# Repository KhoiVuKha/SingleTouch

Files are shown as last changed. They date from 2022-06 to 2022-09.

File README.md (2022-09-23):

# SingleTouch
- This project using Capacitive Sensor buttons to capture human touch (ADC values).
- These ADC values are read by some chip's ADC Pins.
- Each Sensor button is configured as a keyboard's key.
- STM32C8T6 processes touch evens and send it to a Computer through USB connection.
- So our product now acts as an USB HID (USB human interface device class) (In another words It is 'a simple keyboard USB version', each sensor button is a key button).
- With this product, we can play many basic games like: Piano (8 keys), Chicken invaders, Pacman...
Some Images:

# Schematic & PCB:
## Schematic


## PCB
Top Layer | Bottom Layer
--|--
 | 

# Product's real Image
- Product is simply as a PCB board with main chip (STM32C8T6 - with intergrated USB interface) and some holes (Capacitive Sensor Buttons)

| Green PCB (v1.0)  | Red PCB (V1.1) |
| --- | --- |
|  | b635873c06c9c2979bd8 |

- Game Pad

TAY_CAM

- Connected with wires connected to objects

| #  | # |
| --- | --- |
|   |   |
|   |   |
|   |   |

# Techniques / Technologies
- Capacitive Sensor Button

  A capacitive sensor is an electronic device that can detect solid or liquid targets without physical contact. To detect these targets, capacitive sensors emit an electrical field from the sensing end of the sensor. Any target that can disrupt this electrical field can be detected by a capacitive sensor

<p align="center">
  
</p>

- Capacitive sensing

  In electrical engineering, capacitive sensing is a technology, based on capacitive coupling, that can detect and measure anything that is conductive or has a dielectric different from air. Refer to [Wiki](https://en.wikipedia.org/wiki/Capacitive_sensing).

- Hardware design.
- C Programming Language.
- USB HID programming.
- Embedded C & STM32 MicroController: ADC, UART, USB, GPIO...
- Probability statistics theory.

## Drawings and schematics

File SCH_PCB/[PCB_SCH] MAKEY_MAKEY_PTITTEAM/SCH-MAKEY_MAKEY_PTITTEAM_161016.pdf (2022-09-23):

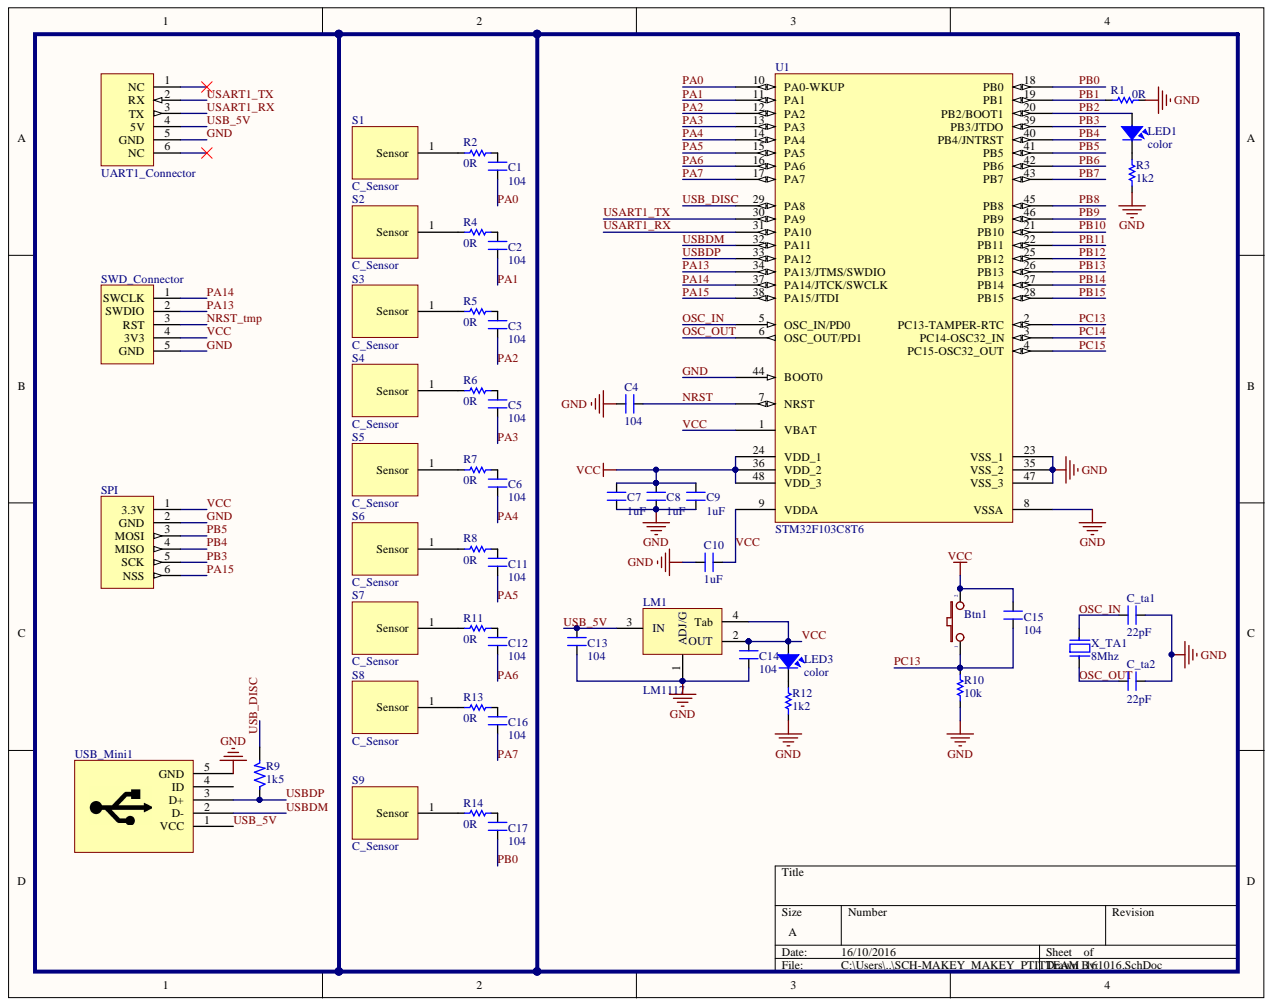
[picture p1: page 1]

3 6 | 3 5
4 8 | 4 7

Size A | Nu m ber | Revisio n

Date: 1 6/1 0/2 0 1 6 | Sheet o f
File: C:\Users\..\SCH-MAKEY_MAKEY_PTITTEAM_ Drawn B1y6: | 1 0 1 6.SchDo c

Comment | Description | Designator | Footprint | LibRef | Quantity
Function | Switch button 2 pin | Btn1 | Button_SMD_2pin | Button_SMD_2pin | 1
104 | Cap SMD, Cap SMD, Cap SMD, Cap SMD, Cap SMD, Cap SMD, Cap SMD, Cremic For Xtal 1pF => 100pF, Cap SMD, Cap SMD, Cap SMD, Cremic For Xtal 1pF => 100pF, Cremic For Xtal 1pF => 100pF | C1, C2, C3, C4, C5, C6, C11, C12, C13, C14, C15, C16, C17 | CAP-0603 | CM, CM, CM, CM, CM, CM, CM, CN0, CM, CM, CM, CN0, CN0 | 13
1uF | Cremic For Xtal 1pF => 100pF, Cremic For Xtal 1pF => 100pF, Cap SMD, Cap SMD | C7, C8, C9, C10 | CAP-0603 | CN0, CN0, CM, CM | 4
22pF | Cremic For Xtal 1pF => 100pF | C_ta1, C_ta2 | CAP-0603 | CN0 | 2
color | Led smd | LED1, LED3 | LED-0805 | Led_SMD | 2
LM1117 | 3v3 | LM1 | SOT223-4N | LM1117 | 1
0R | Resistor smd 0603 type | R1, R2, R4, R5, R6, R7, R8, R11, R13, R14 | RES-0603 | Res_SMD_0603 | 10
1k2 | Resistor smd 0603 type | R3, R12 | RES-0603 | Res_SMD_0603 | 2
1k5 | Resistor 1/4W | R9 | RES-0603 | R | 1
10k | Resistor smd 0603 type | R10 | RES-0603 | Res_SMD_0603 | 1
C_Sensor | | S1, S2, S3, S4, S5, S6, S7, S8, S9 | SOP2 | C_Sensor | 9
| | SPI | JP6 | SPI_Connector | 1
| | SWD_Connector | JP_5 | Load_Program | 1
STM32F103C8T6 | STM32 ARM-based 32-bit MCU with 64 Kbytes Flash, 48-pin LQFP, Industrial Temperature | U1 | LQFP48_N | STM32F103C8T6 | 1
Connector | Connector to USB2Com module | UART1_Connector | JP6 | USB2Com_Conn | 1
| | USB_Mini1 | Micro_USB | USB_M | 1
8Mhz | Crystal For all Crystal 2piX_TA1 | | XT2 | XT2 | 1

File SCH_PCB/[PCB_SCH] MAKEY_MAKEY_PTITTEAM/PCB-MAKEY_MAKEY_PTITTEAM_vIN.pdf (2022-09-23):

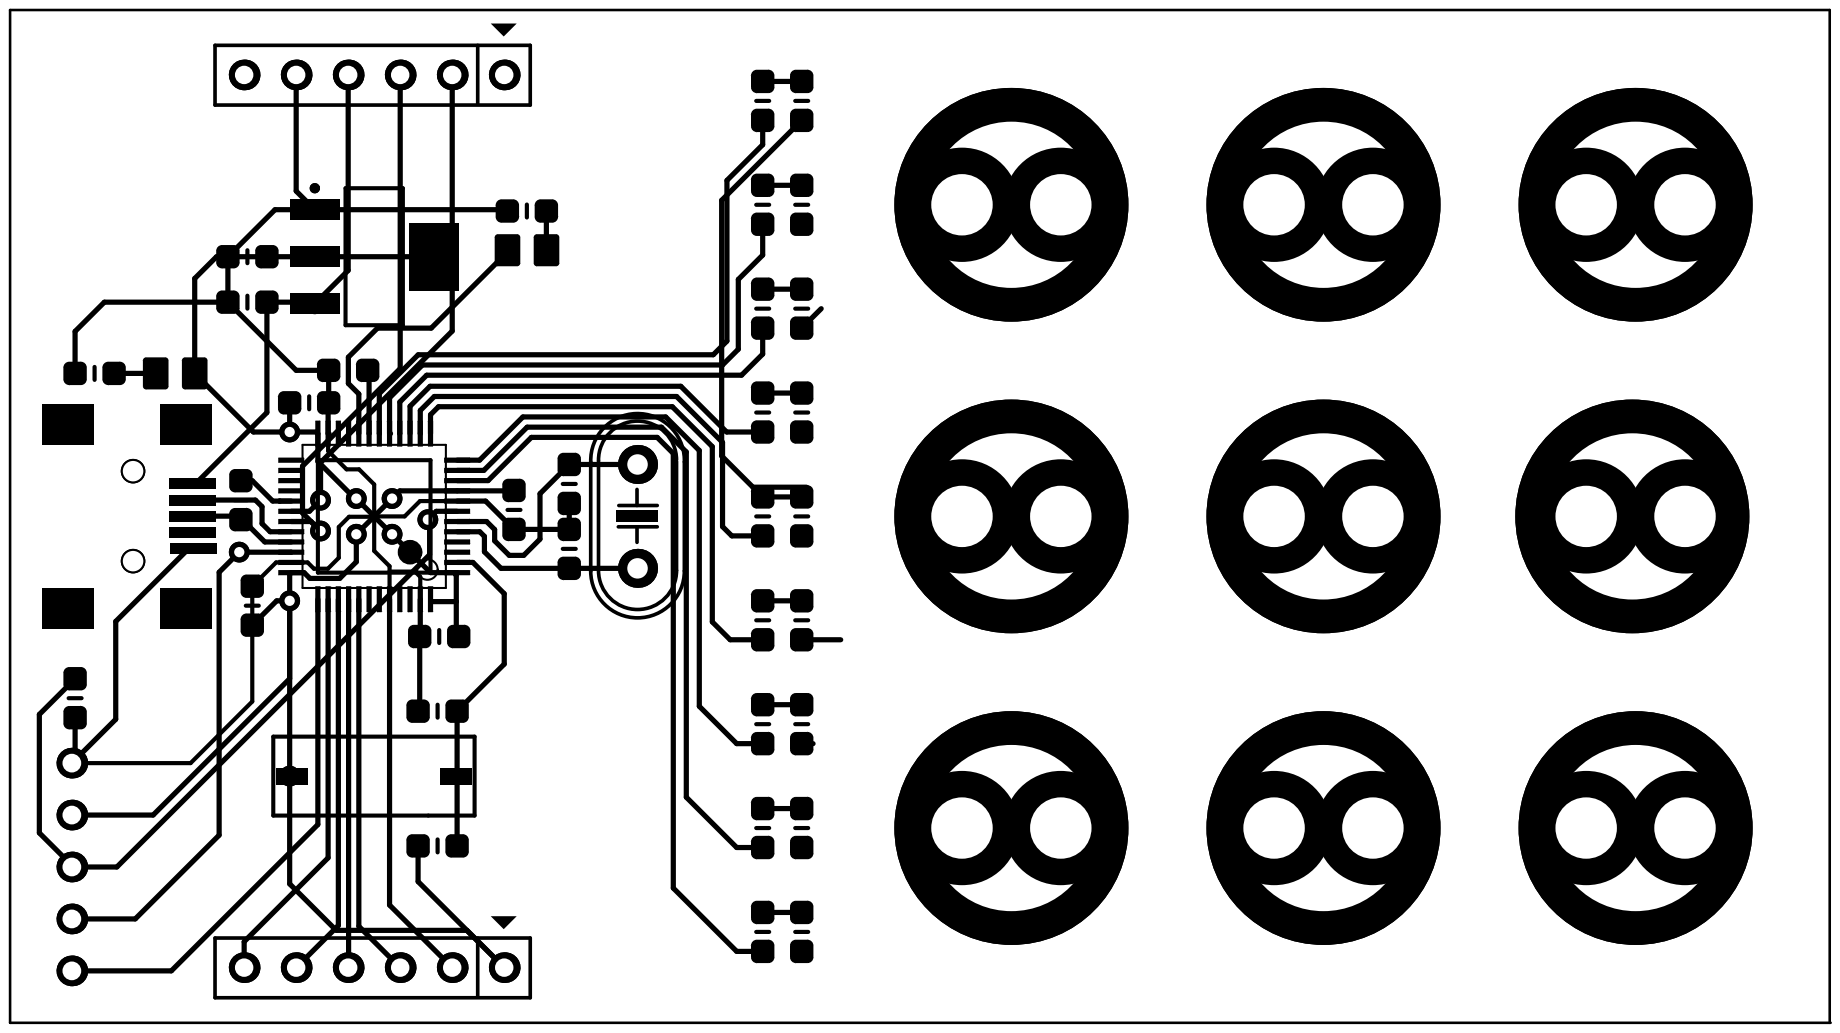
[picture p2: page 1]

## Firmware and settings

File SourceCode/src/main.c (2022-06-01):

/*******************************************************************************************************
  Step    TIM2 event    CCR_VALUE       DMA1    DMA transfer

  1       _UP	          0	              _CH2	  ADC1_JSQR_mem         []  -->  ADC1_JSQR
  2       _CH2	        10	            _CH7	  TIM2_SR_mem           []  -->  TIM2_SR 	        tim2_isr()
  3       _CH1	        200	            _CH5	  GPIOA_CRL_mem         []  -->  GPIOA_CRL
  4       _CH3	        201	            _CH1	  tim2_isr_channel_x_mem[]  -->  tim2_isr_func

                        ARR = 180*2 - 1

                                        _CH4	  channelAccSum         []  -->   channelValue[]
*********************************************************************************************************/
#include <libopencm3/stm32/rcc.h>
#include <libopencm3/stm32/gpio.h>
#include <libopencm3/stm32/usart.h>
#include <libopencm3/stm32/adc.h>
#include <libopencm3/stm32/timer.h>
#include <libopencm3/stm32/flash.h>
#include <libopencm3/cm3/nvic.h>
#include <libopencm3/stm32/dma.h>
#include <libopencm3/cm3/dwt.h>
#include <libopencm3/cm3/scb.h>
#include <libopencm3/cm3/vector.h>

#include <stdio.h>
#include <math.h>

#include "clock.h"
#include "usb.h"
#include "elog.h"
#include "keyboard.h"
#include "keymap.h"
#include "usb_keycode.h"


#define         NOP()                       __asm("nop")
#define         NOP_A()  { /*NOP(); /*NOP(); NOP(); NOP();*/}
#define         NOP_B()  { /*NOP(); NOP(); NOP(); NOP();*/ }
#define         NOP_C()  { /*NOP(); NOP(); NOP(); NOP();*/ }

#define         _FOR_CHANNEL_(inst)         for (int channel = 0; channel < CHANNEL_N; channel++) { inst }

// GPIO Mode define
#define         GPIO_PINMODE(pin, mode)     ((mode) << (((pin) & (8-1))*4))
#define         GPIO_PINMODE_AIN(pin)       GPIO_PINMODE(pin, 0b0000)       // Analog Input
#define         GPIO_PINMODE_IPUD(pin)      GPIO_PINMODE(pin, 0b1000)       // Input Pull-Up or -Down

#define         GPIO_PINMODE_OPP2M(pin)     GPIO_PINMODE(pin, 0b0010)       // Output Push-Pull  2 MHz
#define         GPIO_PINMODE_OPP10M(pin)    GPIO_PINMODE(pin, 0b0001)       // Output Push-Pull 10 MHz
#define         GPIO_PINMODE_OPP50M(pin)    GPIO_PINMODE(pin, 0b0011)       // Output Push-Pull 50 MHz

#define         GPIO_PINMODE_OPP2M_ALL  \
(               GPIO_PINMODE_OPP2M(0)   \
              | GPIO_PINMODE_OPP2M(1)   \
              | GPIO_PINMODE_OPP2M(2)   \
              | GPIO_PINMODE_OPP2M(3)   \
              | GPIO_PINMODE_OPP2M(4)   \
              | GPIO_PINMODE_OPP2M(5)   \
              | GPIO_PINMODE_OPP2M(6)   \
              | GPIO_PINMODE_OPP2M(7)   \
)

#define  GPIO_PINMODE_MASK(pin)      (0b1111 << (((pin) & (8-1))*4))
#define  GPIO_MEASURE_PIN(pin)       (GPIO_PINMODE_AIN(pin) | (GPIO_PINMODE_OPP2M_ALL & ~GPIO_PINMODE_MASK(pin)))

// ADC1 Register define
#define         ADC1_CR2_BASE                  \
(                                              \
                ADC_CR2_ADON                   \
              | ADC_CR2_CONT                   \
              | ADC_CR2_ALIGN_LEFT             \
              | ADC_CR2_EXTSEL_SWSTART         \
              | ADC_CR2_JEXTSEL_JSWSTART       \
              | ADC_CR2_JEXTTRIG               \
)

#define         STAT_N                           (1024L/2)
#define         CALIBRATE_N                      (1024L)
#define         AVERAGE                          (498) // 498
#define         SCALE                            (AVERAGE*8)
#define         CHANNEL_N                        8

#define         THRESHOLD_HI                         10*SCALE       // stm32 pin -> wire -> res 10k -> cap 104 -> thLED
#define         THRESHOLD_LOW                        9*SCALE       // stm32 pin -> wire -> res 10k -> cap 104 -> thLED

// For Timer2
#define         ARR_VALUE                        (180*2-1)        // Thoi gian giua 2 lan nhay vao ngat
#define         PSC_VALUE                        (1*1-1)          // CK_CNT = PCLK / (PSC[15:0] + 1)
// TIM2_CH1
#define         CCR1_VALUE                       200


// TIM2_CH2
#define         CCR2_VALUE                       10
// TIM2_CH3
#define         CCR3_VALUE                       201


//----------------------------------For DMA-------------------------------------
#define         DMA_CCR_SRC_PERIPHERAL            ((uint32_t)(0x00000000))
#define         DMA1_CH1                          DMA1, DMA_CHANNEL1
#define         DMA1_CH2                          DMA1, DMA_CHANNEL2
#define         DMA1_CH4                          DMA1, DMA_CHANNEL4
#define         DMA1_CH5                          DMA1, DMA_CHANNEL5
#define         DMA1_CH7                          DMA1, DMA_CHANNEL7

// DMAy Channelx CCR - Chon cac cau hinh
#define         DMA1_CHANNEL4_CCR_BASE  \
(                                       \
                DMA_CCR_SRC_PERIPHERAL  \
              | DMA_CCR_PINC            \
              | DMA_CCR_MINC            \
              | DMA_CCR_PSIZE_32BIT     \
              | DMA_CCR_MSIZE_32BIT     \
              | DMA_CCR_PL_MEDIUM       \
              | DMA_CCR_MEM2MEM         \
)

//==========================================================
// Khai bao cac ham
void UART1_Init_A9A10();
void PrintADC1Info();
void PrintSystemInfo();

volatile uint32_t flag = 0;

// Global variable
int32_t channelData[CHANNEL_N*3];
#define  channelValue       (channelData + 0*CHANNEL_N)
#define  channelAccSum      (channelData + 1*CHANNEL_N)
#define  channelBaseline    (channelData + 2*CHANNEL_N)

uint32_t GPIOA_CRL_mem[1] = { GPIO_PINMODE_OPP2M_ALL };
uint32_t TIM2_SR_mem[1] = { 0 };
uint32_t ADC1_JSQR_mem[CHANNEL_N] =
{
  (ADC_CHANNEL0 << (5*3)),
  (ADC_CHANNEL1 << (5*3)),
  (ADC_CHANNEL2 << (5*3)),
  (ADC_CHANNEL3 << (5*3)),
  (ADC_CHANNEL4 << (5*3)),
  (ADC_CHANNEL5 << (5*3)),
  (ADC_CHANNEL6 << (5*3)),
  (ADC_CHANNEL7 << (5*3)),
};

vector_table_t __attribute__((aligned(512))) VectorTableRAM;

//==========================================================
event_t key[8] =
{
  //_K(A), _K(B), _K(C), _K(D), _K(E), _K(F), _K(G), _K(H)
  //_K(L), _K(H), _K(E), _K(O), _K(I), _K(T), _K(O), _K(E)

  //_K(SPACE), _K(BACKSPACE), _K(SPACE), _K(BACKSPACE), _K(E), _K(BACKSPACE), _K(SPACE), _K(LEFT)
  _K(W), _K(A), _K(DOWN), _K(LEFT), _K(RIGHT), _K(S), _K(UP), _K(SPACE)
};

void keyboard_event_touch(event_t *event, bool pressed)
{
  uint8_t key = event->key.code;

  elog("key %02x %d\n", key, pressed);

  switch (key) {
  case KEY_LCTRL ... KEY_RGUI:
      if (pressed) {
          keyboard_add_modifier(key);
      } else {
          keyboard_del_modifier(key);
      }
      break;

  default:
      if (pressed) {
          keyboard_add_key(key);
      } else {
          keyboard_del_key(key);
      }
      break;
  }

//  if (keyboard_dirty) {
//      usb_update_keyboard(&keyboard_state);
//      keyboard_dirty = false;
//  }

  if (nkro_dirty) {
      usb_update_nkro(&nkro_state);
      nkro_dirty = false;
  }
}


//==========================================================
void delay_us(uint32_t micros)
{
  uint32_t t0 = dwt_read_cycle_counter();
  uint32_t delta = 72 * micros;
  while ((dwt_read_cycle_counter() - t0) < delta);
}

void delay_ms(unsigned long ms)
{
  for (; ms; ms--)
  {
    delay_us(1000);
  }
}


uint64_t dwt_CycleCount64()
{
  static uint64_t last_cycle_count_64 = 0;
  last_cycle_count_64 += DWT_CYCCNT - (uint32_t)(last_cycle_count_64);
  return last_cycle_count_64;
}

uint64_t dwt_Millis()
{
  return dwt_CycleCount64() / 72000;
}

uint64_t dwt_Micros()
{
  return dwt_CycleCount64() / 72;
}

//==========================================================

void RCC_Config(void)
{
  // System clock
  rcc_clock_setup_in_hse_8mhz_out_72mhz();
  flash_set_ws(FLASH_ACR_LATENCY_1WS);

  // Enable clock GPIO
  rcc_periph_clock_enable(RCC_GPIOA);
  rcc_periph_clock_enable(RCC_GPIOB);
  rcc_periph_clock_enable(RCC_GPIOC);
  rcc_periph_clock_enable(RCC_AFIO);

   // Enable clock for Timer 2
  rcc_periph_clock_enable(RCC_TIM2);

  // Enable clock for ADC
  rcc_periph_clock_enable(RCC_ADC1);
  adc_power_off(ADC1);
  rcc_periph_reset_pulse(RST_ADC1);
  rcc_set_adcpre(RCC_CFGR_ADCPRE_PCLK2_DIV2);

  // Enable clock DMA
  rcc_periph_clock_enable(RCC_DMA1);
}

//==========================================================

void GPIO_Config()
{
  //*************** Used pins *****************
  // GPIOA
  gpio_set_mode(GPIOA, GPIO_MODE_INPUT, GPIO_CNF_INPUT_ANALOG,
                GPIO0 | GPIO1 | GPIO2 | GPIO3 |
                GPIO4 | GPIO5 | GPIO6 | GPIO7);
  GPIOA_ODR |= GPIO0 | GPIO1 | GPIO2 | GPIO3 | GPIO4 | GPIO5 | GPIO6 | GPIO7;
  // A8 OutPP High
  gpio_set_mode(GPIOA, GPIO_MODE_OUTPUT_2_MHZ, GPIO_CNF_OUTPUT_PUSHPULL, GPIO8);
  gpio_set(GPIOA, GPIO8);
  // GPIOB
  gpio_set_mode(GPIOB, GPIO_MODE_INPUT, GPIO_CNF_INPUT_ANALOG, GPIO1);
  gpio_set_mode(GPIOB, GPIO_MODE_OUTPUT_2_MHZ, GPIO_CNF_OUTPUT_PUSHPULL, GPIO2);
  gpio_set_mode(GPIOB, GPIO_MODE_OUTPUT_2_MHZ, GPIO_CNF_OUTPUT_PUSHPULL, GPIO0);
  GPIOB_ODR |= 0x04;    // Bat Led B2
  GPIOB_ODR &= ~0x01;   // Xuat muc 0 o chan B0
  // GPIOC
  //gpio_set_mode(GPIOC, GPIO_MODE_INPUT, GPIO_CNF_INPUT_FLOAT,
  //              GPIO14);
  //*************** Unused pins ****************
  // GPIOA - Input Pull Down Pins
  gpio_set_mode(GPIOA, GPIO_MODE_INPUT, GPIO_CNF_INPUT_PULL_UPDOWN,
                GPIO11 | GPIO12 | GPIO13 | GPIO14 | GPIO15);
  // GPIOB - Input Pull Down Pins
  gpio_set_mode(GPIOB, GPIO_MODE_INPUT, GPIO_CNF_INPUT_PULL_UPDOWN,
                GPIO3  | GPIO4  | GPIO5  |
                GPIO6  | GPIO7  | GPIO8  | GPIO9  |
                GPIO10 | GPIO11 | GPIO12 | GPIO13 |
                GPIO14 | GPIO15);
  // GPIOC - Input Pull Down Pins
  gpio_set_mode(GPIOC, GPIO_MODE_INPUT, GPIO_CNF_INPUT_PULL_UPDOWN,
                GPIO13 | GPIO14|  GPIO15);
}

//==========================================================

void UART1_Init_A9A10(int baudrate)
{
  rcc_periph_clock_enable(RCC_USART1);
  rcc_periph_clock_enable(RCC_GPIOA);

	// Setup GPIO pin GPIO_USART1_TX and GPIO_USART1_RX.
	gpio_set_mode(GPIOA, GPIO_MODE_OUTPUT_2_MHZ,
                       GPIO_CNF_OUTPUT_ALTFN_PUSHPULL, GPIO_USART1_TX);
	gpio_set_mode(GPIOA, GPIO_MODE_INPUT,
                       GPIO_CNF_INPUT_FLOAT, GPIO_USART1_RX);

	// Setup UART parameters.
	usart_set_baudrate(USART1, baudrate);
	usart_set_databits(USART1, 8);
	usart_set_stopbits(USART1, USART_STOPBITS_1);
	usart_set_parity(USART1, USART_PARITY_NONE);
	usart_set_flow_control(USART1, USART_FLOWCONTROL_NONE);
	usart_set_mode(USART1, USART_MODE_TX_RX);

	// Finally enable the USART.
	usart_enable(USART1);

	// Disable buffering on stdout by using setbuf
	// fix printf not flush after the call unless a newline is in format tring
	setbuf(stdout, NULL);

}

//==========================================================

int _write(int file, char *ptr, int len)
{
  for (int i = len; i > 0; i--)
  {
    while ((USART1_SR & USART_CR1_TXEIE) == 0);
    USART1_DR = *ptr++;
  }
  return len;
}

//==========================================================

void usb_wakeup_isr(void) {
  usb_poll();
  flag = 1;
}

void usb_lp_can_rx0_isr(void) {
  usb_poll();
  flag = 1;
}

//====================================================================

void DMAchannel4_config()
{
  dma_channel_reset(DMA1_CH4);                                  // Reset to default values

  dma_set_peripheral_address(DMA1_CH4, (int32_t)channelAccSum); // SRC: int32_t channelAccSum[++]
  dma_set_peripheral_size(DMA1_CH4, DMA_CCR_PSIZE_32BIT);       //      int32_t
  dma_enable_peripheral_increment_mode(DMA1_CH4);               //                           [++]

  dma_set_memory_address(DMA1_CH4, (int32_t)channelValue);      // DST: int32_t  channelValue[++]
  dma_set_memory_size(DMA1_CH4, DMA_CCR_MSIZE_32BIT);           //      int32_t
  dma_enable_memory_increment_mode(DMA1_CH4);                   //                           [++]

  dma_set_number_of_data(DMA1_CH4, CHANNEL_N*2);                // Transfer Count: CHANNEL_N*2
  dma_set_read_from_peripheral(DMA1_CH4);                       // Periph --> Mem
  dma_set_priority(DMA1_CH4, DMA_CCR_PL_MEDIUM);                // Medium priority
  dma_enable_mem2mem_mode(DMA1_CH4);                            // Mem to Mem copy
  //dma_enable_circular_mode(DMA1_CH4);                         // non-circular mode
}

void DMAchannel2_TIM2_UP_config()
{
  dma_channel_reset(DMA1_CH2);                                  // Reset to default values

  dma_set_memory_address(DMA1_CH2, (uint32_t)ADC1_JSQR_mem);    // SRC: uint32_t ADC1_JSQR_mem[++]
  dma_set_memory_size(DMA1_CH2, DMA_CCR_MSIZE_32BIT);           //      uint32_t
  dma_enable_memory_increment_mode(DMA1_CH2);                   //                            [++]

  dma_set_peripheral_address(DMA1_CH2, (uint32_t)&ADC1_JSQR);   // DST: uint32_t &ADC1_JSQR
  dma_set_peripheral_size(DMA1_CH2, DMA_CCR_PSIZE_32BIT);       //      uint32_t
  dma_disable_peripheral_increment_mode(DMA1_CH2);              //

  dma_set_number_of_data(DMA1_CH2, CHANNEL_N);                  // Transfer Count: CHANNEL_N
  dma_set_read_from_memory(DMA1_CH2);                           // Mem --> Peripheral
  dma_set_priority(DMA1_CH2, DMA_CCR_PL_MEDIUM);                // Medium priority

  //dma_enable_mem2mem_mode(DMA1_CH2);                          // Mem to Mem copy disable
  dma_enable_circular_mode(DMA1_CH2);                           // circular mode

  dma_enable_channel(DMA1_CH2);                                 // Enable DMA1 Channel 2 transfer

}

void DMAchannel7_TIM2_CH2_config()
{
  dma_channel_reset(DMA1_CH7);                                  // Reset to default values

  dma_set_memory_address(DMA1_CH7, (uint32_t)TIM2_SR_mem);      // SRC: uint32_t TIM2_SR_mem[]
  dma_set_memory_size(DMA1_CH7, DMA_CCR_MSIZE_32BIT);           //      uint32_t
  dma_disable_memory_increment_mode(DMA1_CH7);

  dma_set_peripheral_address(DMA1_CH7, (uint32_t)&TIM2_SR);     // DST: uint32_t &TIM2_SR
  dma_set_peripheral_size(DMA1_CH7, DMA_CCR_PSIZE_32BIT);       //      uint32_t
  dma_disable_peripheral_increment_mode(DMA1_CH7);              //

  dma_set_number_of_data(DMA1_CH7, 1);                          // Transfer Count: 1
  dma_set_read_from_memory(DMA1_CH7);                           // Mem --> Peripheral
  dma_set_priority(DMA1_CH7, DMA_CCR_PL_MEDIUM);                // Medium priority

  //dma_enable_mem2mem_mode(DMA1_CH7);                          // Mem to Mem copy disable
  dma_enable_circular_mode(DMA1_CH7);                           // circular mode

  dma_enable_channel(DMA1_CH7);                                 // Enable DMA1 Channel 7 transfer

}

void DMAchannel5_TIM2_CH1_config()
{
  dma_channel_reset(DMA1_CH5);                                  // Reset to default values

  dma_set_memory_address(DMA1_CH5, (uint32_t)GPIOA_CRL_mem);    // SRC: uint32_t GPIOA_CRL_mem[]
  dma_set_memory_size(DMA1_CH5, DMA_CCR_MSIZE_32BIT);           //      uint32_t
  dma_disable_memory_increment_mode(DMA1_CH5);

  dma_set_peripheral_address(DMA1_CH5, (uint32_t)&GPIOA_CRL);   // DST: uint32_t &GPIOA_CRL
  dma_set_peripheral_size(DMA1_CH5, DMA_CCR_PSIZE_32BIT);       //      uint32_t
  dma_disable_peripheral_increment_mode(DMA1_CH5);

  dma_set_number_of_data(DMA1_CH5, 1);                          // Transfer Count: 1
  dma_set_read_from_memory(DMA1_CH5);                           // Mem --> Peripheral
  dma_set_priority(DMA1_CH5, DMA_CCR_PL_MEDIUM);                // Medium priority

  //dma_enable_mem2mem_mode(DMA1_CH5);                          // Mem to Mem copy disable
  dma_enable_circular_mode(DMA1_CH5);                           // circular mode

  dma_enable_channel(DMA1_CH5);                                 // Enable DMA1 Channel 5 transfer
}

void (*tim2_isr_func)();
uint32_t tim2_isr_channel_x_mem[CHANNEL_N];
void DMAchannel1_TIM2_CH3_config()
{
  dma_channel_reset(DMA1_CH1);                                          // Reset to default values

  dma_set_memory_address(DMA1_CH1, (uint32_t)tim2_isr_channel_x_mem);   // SRC: uint32_t tim2_isr_channel_x_mem[++]
  dma_set_memory_size(DMA1_CH1, DMA_CCR_MSIZE_32BIT);                   //      uint32_t
  dma_enable_memory_increment_mode(DMA1_CH1);                           //                                     [++]

  dma_set_peripheral_address(DMA1_CH1, (uint32_t)&tim2_isr_func);       // DST: uint32_t &tim2_isr_func
  dma_set_peripheral_size(DMA1_CH1, DMA_CCR_PSIZE_32BIT);               //      uint32_t
  dma_disable_peripheral_increment_mode(DMA1_CH1);                      //

  dma_set_number_of_data(DMA1_CH1, CHANNEL_N);                          // Transfer Count: CHANNEL_N
  dma_set_read_from_memory(DMA1_CH1);                                   // Mem --> Peripheral
  dma_set_priority(DMA1_CH1, DMA_CCR_PL_MEDIUM);                        // Medium priority

  //dma_enable_mem2mem_mode(DMA1_CH1);                                  // Mem to Mem copy disable
  dma_enable_circular_mode(DMA1_CH1);                                   // circular mode

  dma_enable_channel(DMA1_CH1);                                         // Enable DMA1 Channel 1 transfer

}

void ADC_Config()
{
  adc_set_dual_mode(ADC_CR1_DUALMOD_IND);                           // ADC1 and ADC2 operate independently
  adc_set_left_aligned(ADC1);                                       // Data Align Left

  // Regular channel
  uint8_t regularChannels[] = {ADC_CHANNEL9};
  adc_set_regular_sequence(ADC1, 1, regularChannels);
  adc_set_sample_time(ADC1, regularChannels[0], ADC_SMPR_SMP_239DOT5CYC); // Set Sample Time Regular Channel 9
  adc_enable_external_trigger_regular(ADC1, ADC_CR2_EXTSEL_SWSTART);
  adc_set_continuous_conversion_mode(ADC1);                         // Continuous Conversion mode

  // Injected channel
  uint8_t injectedChannels[] = {ADC_CHANNEL0};
  adc_set_injected_sequence(ADC1, 1, injectedChannels);             // Set sequence length = 1 injected Channel

  _FOR_CHANNEL_( adc_set_sample_time(ADC1, channel, ADC_SMPR_SMP_1DOT5CYC); ) // Set Sample Time Injected Channel 0 - 7

  adc_enable_external_trigger_injected(ADC1, ADC_CR2_JEXTSEL_JSWSTART);

  adc_power_on(ADC1);                                               // Enable ADC1
  adc_reset_calibration(ADC1);                                      // Reset Calibration & wait reset finish
  adc_calibration(ADC1);                                            // Calibration & wait Calibration finish

  adc_start_conversion_regular(ADC1);
}

void NVIC_Congfig()
{
  scb_set_priority_grouping(SCB_AIRCR_PRIGROUP_GROUP16_NOSUB);

  nvic_enable_irq(NVIC_TIM2_IRQ);
  nvic_set_priority(NVIC_TIM2_IRQ, 0 << 4);

 	nvic_enable_irq(NVIC_USB_LP_CAN_RX0_IRQ);
  nvic_set_priority(NVIC_USB_LP_CAN_RX0_IRQ, 4 << 4);

	nvic_enable_irq(NVIC_USB_WAKEUP_IRQ);
	nvic_set_priority(NVIC_USB_WAKEUP_IRQ, 5 << 4);

}
//==========================================================

void TIM2_Config()
{
  TIM2_PSC    = PSC_VALUE;                             // Prescaler value
  TIM2_ARR    = ARR_VALUE;                             // Auto - reload value

  //------------- TIM2_CH1------------
  TIM2_CCR1   = CCR1_VALUE;                            // gia tri so sanh Capture/cpmpare 1
  TIM2_DIER  |= TIM_DIER_CC1DE;

  //-------------TIM2_CH2-------------
  TIM2_CCR2   = CCR2_VALUE;                            // gia tri so sanh Capture/cpmpare 2
  TIM2_DIER  |= TIM_DIER_CC2DE;
  timer_enable_irq(TIM2, TIM_SR_CC2IF);                // Cho phep ngat compare CH2

  //------------- TIM2_CH3------------
  TIM2_CCR3   = CCR3_VALUE;                            // gia tri so sanh Capture/cpmpare 3
  TIM2_DIER  |= TIM_DIER_CC3DE;

  //------------- TIM2_UP------------
  TIM2_DIER  |= TIM_DIER_UDE;

  TIM2_CR1    = TIM_CR1_DIR_UP | TIM_CR1_CEN;          // Upcounting mode, Counter enable
}
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
int main(void)
{
  dwt_enable_cycle_counter();
  clock_init();
  RCC_Config();
  GPIO_Config();
  serial_active = false;
  UART1_Init_A9A10(250000);
  usb_init();
  DMAchannel4_config();
  DMAchannel2_TIM2_UP_config();
  DMAchannel7_TIM2_CH2_config();
  DMAchannel5_TIM2_CH1_config();
  DMAchannel1_TIM2_CH3_config();
  ADC_Config();
  TIM2_Config();
  NVIC_Congfig();

  PrintSystemInfo();

  BaselineCalibrate();

  TCNT_value_min = 1000000; TCNT_value_max = 0; sumTCNT_value = 0; count_TCNT = 0;

  for(int channel = 0; channel < CHANNEL_N; channel++)
  {
    printf("tim2_isr_channel_x_mem[%d] = %X\n", channel, tim2_isr_channel_x_mem[channel] );
  }

  while (true)
  {
    Do_TB_PS_delta();
//    for(int i = 0; i < 8; i++)
//    {
//      printf("keyPress[%d] = %d\t", i, keyPress[i]);
//
//    }
//    printf("\n");

  }
}

//==========================================================

void PrintADC1Info()
{
  printf("ADC1 Init:\n");
  printf("RCC_CFGR = %08lX\n", RCC_CFGR);
  printf("CR1      = %08lX\n", ADC1_CR1);
  printf("CR2      = %08lX\n", ADC1_CR2);
  printf("SMPR1    = %08lX\n", ADC1_SMPR1);
  printf("SMPR2    = %08lX\n", ADC1_SMPR2);
  printf("SQR1     = %08lX\n", ADC1_SQR1);
  printf("SQR2     = %08lX\n", ADC1_SQR2);
  printf("SQR3     = %08lX\n", ADC1_SQR3);
  printf("JSQR     = %08lX\n", ADC1_JSQR);
  printf("\n");
}

void PrintSystemInfo()
{
  printf("SystemInfo:\n");
  printf("SCB_VTOR = %08X\n", SCB_VTOR);
  printf("&SCB_VTOR = %08X\n", &SCB_VTOR);
  printf("FLASH_BASE = %08X\n", FLASH_BASE);
  printf("VectorTableRAM size = %d\n", sizeof(VectorTableRAM));
  printf("&VectorTableRAM = %08X\n", &VectorTableRAM);


  vector_table_t *VectorTableFlash = (vector_table_t*)(FLASH_BASE + SCB_VTOR);

  // Copy VectorTableFlash to VectorTableRAM
  volatile uint32_t *src, *dest;
  src = VectorTableFlash;
  dest = &VectorTableRAM;
	for (int i = 0; i < sizeof(VectorTableRAM)/4; i++, src++, dest++) {
		*dest = *src;
	}

  printf("NVIC_TIM2_IRQ = %08X\n", VectorTableFlash->irq[NVIC_TIM2_IRQ]);
  printf("VectorTableRAM = %08X\n", VectorTableRAM.irq[NVIC_TIM2_IRQ]);
  printf("tim2_isr = %08X\n", &tim2_isr);
  printf("\n");

}

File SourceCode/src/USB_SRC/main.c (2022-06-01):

#include <libopencm3/stm32/rcc.h>
#include <libopencm3/stm32/gpio.h>
#include <libopencm3/stm32/usart.h>
#include <libopencm3/cm3/dwt.h>
#include <libopencm3/cm3/nvic.h>
#include <libopencm3/dispatch/nvic.h>
#include <stdio.h>

#include "clock.h"
#include "usb.h"
#include "elog.h"
#include "keyboard.h"
#include "keymap.h"
#include "usb_keycode.h"


#define DEBOUNCE 10000

// Khai bao cac ham
void UART1_Init_A9A10(void);
int _write(int file, char *ptr, int len);
void RCC_Init(void);
void GPIO_Init(void);
void key_event(bool pressed);
void delay_us(uint32_t micros);
void usb_wakeup_isr(void);
void usb_lp_can_rx0_isr(void);

volatile uint32_t flag = 0;


//==========================================================
void delay_us(uint32_t micros)
{
  uint32_t t0 = dwt_read_cycle_counter();
  uint32_t delta = 72 * micros;
  while ((dwt_read_cycle_counter() - t0) < delta);
}

event_t key[1] =
{
  _K(A)
};

void key_event(bool pressed)
{
  event_t *event = &key[0];
  keyboard_event(event, pressed);
}

//==========================================================
static void mcu_init(void)
{
    rcc_clock_setup_in_hse_8mhz_out_72mhz();
}

void RCC_Init(void)
{
	rcc_periph_clock_enable(RCC_GPIOA);
	rcc_periph_clock_enable(RCC_GPIOB);
}
void GPIO_Init(void)
{
	// A8 OutPP High
    gpio_set_mode(GPIOA, GPIO_MODE_OUTPUT_2_MHZ, GPIO_CNF_OUTPUT_PUSHPULL, GPIO8);
    gpio_set(GPIOA, GPIO8);

	// A0 Input Float
	gpio_set_mode(GPIOA, GPIO_MODE_INPUT, GPIO_CNF_INPUT_FLOAT, GPIO0);

	// B2 OutPP_2Mhz
	gpio_set_mode(GPIOB, GPIO_MODE_OUTPUT_2_MHZ, GPIO_CNF_OUTPUT_PUSHPULL, GPIO2);
	gpio_set(GPIOB, GPIO2);

}

int main(void)
{
	uint16_t count;
	mcu_init();
	clock_init();
	serial_active = false;
	dwt_enable_cycle_counter();
	UART1_Init_A9A10();
	usb_init();

	nvic_enable_irq(NVIC_USB_LP_CAN_RX0_IRQ);
	nvic_enable_irq(NVIC_USB_WAKEUP_IRQ);

	RCC_Init();
	GPIO_Init();
	//printf("Hello World!\n");
  while (1)
  {
    //usb_poll();
    uint16_t btnState = (GPIOA_IDR & (1 << 0));
    if (btnState != 0)
    {
      count ++;
      if(count == DEBOUNCE)
      {
        GPIOB_ODR ^= 0x04;
        key_event(1);

		//delay_us(10000);
		for(int i = 0; i < 8; i++)
		{
			flag = 0;
			while(flag == 0);
		}



        key_event(0);
		printf("Hello World!\n");
      }
      if(count >= DEBOUNCE) count = DEBOUNCE + 1;
    }
    else count = 0;
	//key_event(0);
  }
}

//==========================================================
void usb_wakeup_isr(void) {

  usb_poll();
  flag = 1;
}

void usb_lp_can_rx0_isr(void) {

  usb_poll();
  flag = 1;
}
//==========================================================
void UART1_Init_A9A10()
{
  rcc_periph_clock_enable(RCC_USART1);
  rcc_periph_clock_enable(RCC_GPIOA);

	/* Setup GPIO pin GPIO_USART1_TX and GPIO_USART1_RX. */
	gpio_set_mode(GPIOA, GPIO_MODE_OUTPUT_2_MHZ,
                       GPIO_CNF_OUTPUT_ALTFN_PUSHPULL, GPIO_USART1_TX);
	gpio_set_mode(GPIOA, GPIO_MODE_INPUT,
                       GPIO_CNF_INPUT_FLOAT, GPIO_USART1_RX);

	/* Setup UART parameters. */
	usart_set_baudrate(USART1, 250000);
	usart_set_databits(USART1, 8);
	usart_set_stopbits(USART1, USART_STOPBITS_1);
	usart_set_parity(USART1, USART_PARITY_NONE);
	usart_set_flow_control(USART1, USART_FLOWCONTROL_NONE);
	usart_set_mode(USART1, USART_MODE_TX_RX);

	/* Finally enable the USART. */
	usart_enable(USART1);

}

//==========================================================

//==========================================================
int _write(int file, char *ptr, int len)
{
  for (int i = len; i != 0; i--)
  {
    while ((USART1_SR & USART_CR1_TCIE) == 0)
    {
      //usb_poll();
    }
    USART1_DR = *ptr++;
  }
  return len;
}

//==========================================================
